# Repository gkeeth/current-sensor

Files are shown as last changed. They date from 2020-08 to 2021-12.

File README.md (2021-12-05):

# current-sensor
Hall effect current sensor board. Invasive (connected in series with DUT), with BNC output to oscilloscope.

Designed to fit in Hammond 1593W enclosure. Powered by 9V battery. Includes PCBs for front and back panels (20A and 36A options for front panel).

## Specifications:
- Output: 0-5V, DC-coupled
- Maximum input current: +/-20A. Different current limits are possible by
selecting a different version of the ACS730 Hall effect IC (also changes sensitivity)
  - ACS730xxxxx-20AB: +/- 20A
  - ACS730xxxxx-40AB: +/- 40A [limited to 36A by binding posts]
- Gain: selectable between x1, x10, and x100
  - -20AB: x1 (100mV/A), x10 (1V/A), and x100 (10V/A)
  - -40AB: x1 (50mV/A), x10 (500mV/A), and x100 (5V/A)
- Bandwidth: selectable between 1kHz, 10kHz, and 100kHz
- Power supply: 9V battery

## Adjustment Procedure:
The only adjustment needed is to adjust the zero-current offset voltage so that
the output reads zero when zero current is applied to the input.

1. Disconnect wires from input jacks so that input current is zero.
2. Set Gain to 1x and Bandwidth to 1kHz.
3. Adjust trimmer RV1 until the voltage at the output (between BNC center pin
and shell) is as close to 0V as possible.
4. Increase gain to 10x/100x and fine-tune adjustment.

## Possible Future Improvements:
- use a multi-turn trimpot for zero-current offset adjustment
- make adjustment trimpot available at rear panel for trim without removing case

## Schematic:
[PDF of schematic](pdf/current-sensor.pdf)
schematic

## Layout:
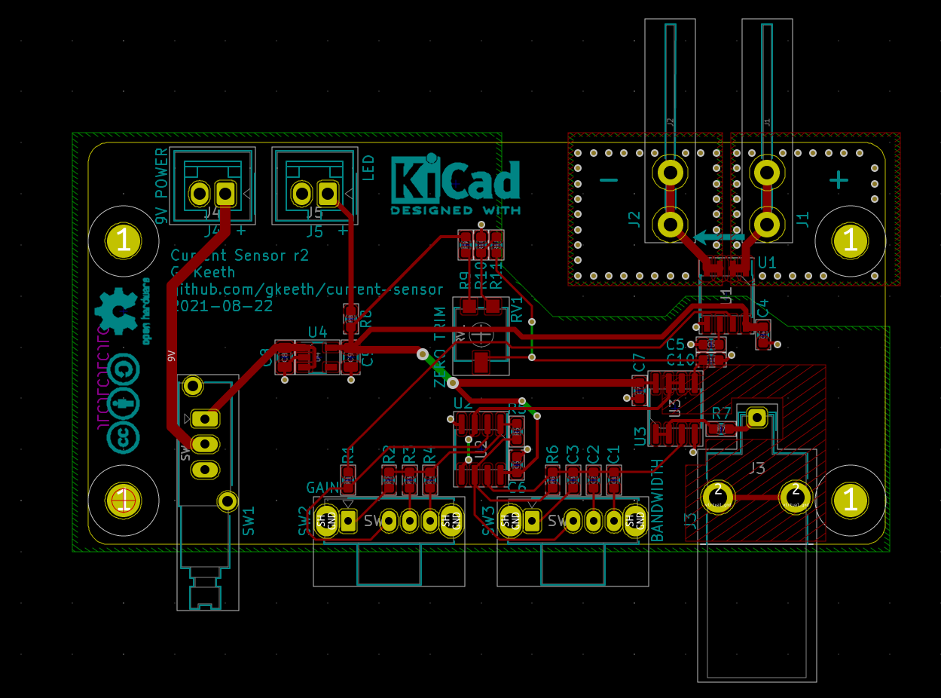
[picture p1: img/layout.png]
layout


## BOM:
[BOM for main board](bom/current-sensor.csv)

### Additional components:
Note that the board was designed with Molex SL crimp terminals for the LED and 9V battery,
but those connections could be done with another crimp family or even soldered. Substitute
connectors as appropriate.

| Quantity | Manufacturer | Manufacturer PN  | Distributor | Distributor PN | Notes |
| --- | --- | --- | --- | --- | --- |
| 1 | Hammond | 1593WBK | Digikey | 164-1593WBK-ND | case |
| 1 | Hammond | 1593ATS50 | Digikey | HM1442-ND | PCB mounting screws  |
| 1 | MPD | BH9VW | Digikey | BH9VW-ND | battery holder |
| 2 | Cal Test | CT2232-4 | Digikey | BKCT2232-4-ND  | binding posts |
| 1 | C&K | G003G | Digikey | 401-1205-ND | power button cap |
| 1 | Lumex | SSI-LXH312ID-150 | Digikey | 67-1190-ND | power LED |
| 2 | Molex | 0190050010 | Digikey | WM18241-ND | QC connectors |
| 4 | Molex | 0016020097 | Digikey | WM2513-ND | SL crimp terminals for LED and battery |
| 2 | Molex | 0050579402 | Digikey | WM2900-ND | SL crimp housings for LED and battery  |

## Front/Rear Panel and Assembly:
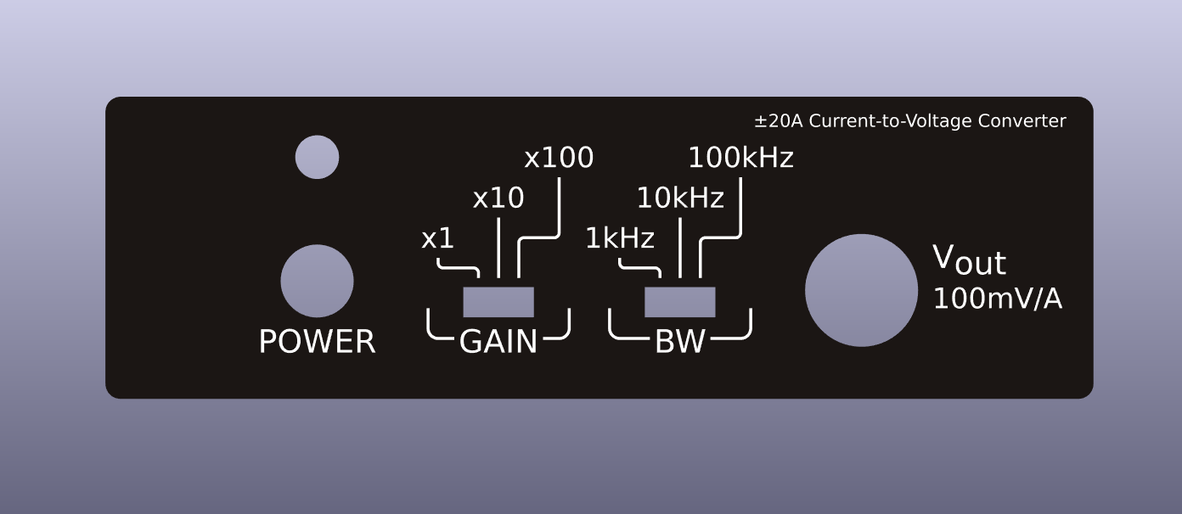
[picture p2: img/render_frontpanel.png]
front panel

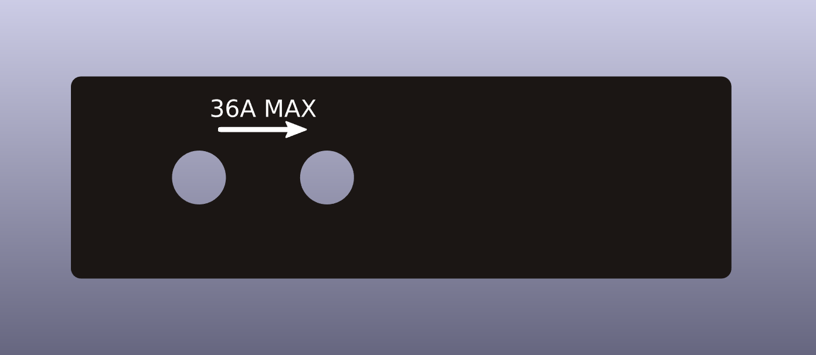
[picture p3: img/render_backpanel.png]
back panel

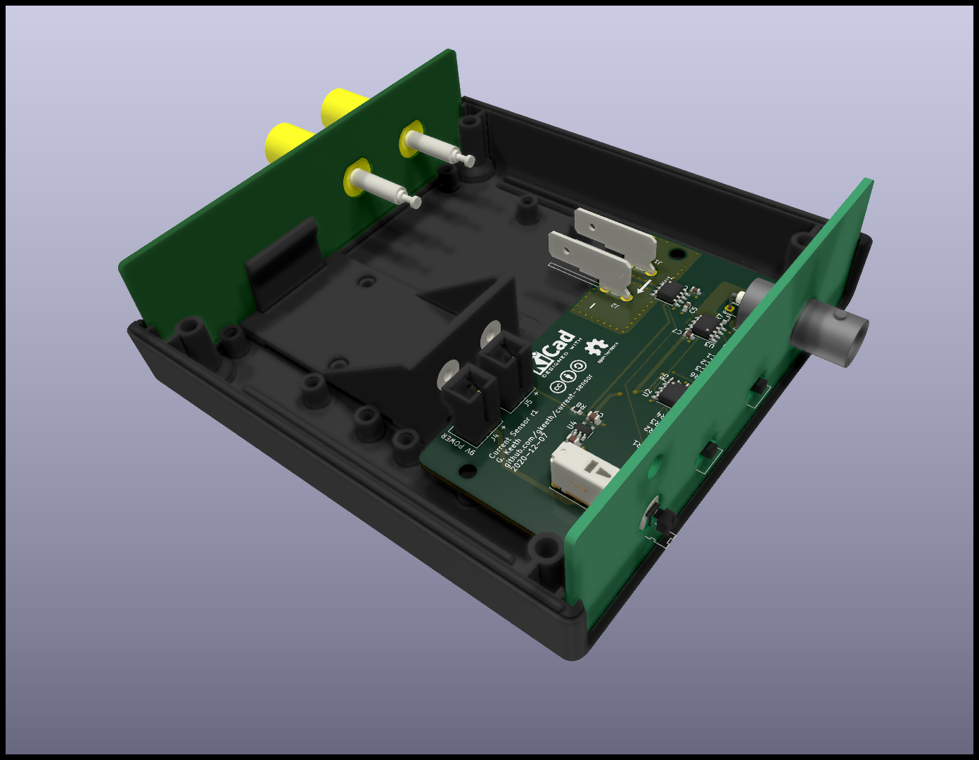
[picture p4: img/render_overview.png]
front render


## License:
Licensed under the [Creative Commons Attribution-ShareAlike 4.0 International License][cc-by-sa].

[][cc-by-sa]

[cc-by-sa]: http://creativecommons.org/licenses/by-sa/4.0/
[cc-by-sa-image]: https://licensebuttons.net/l/by-sa/4.0/88x31.png

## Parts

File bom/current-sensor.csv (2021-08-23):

Source: | /home/graham/Projects/current-sensor/current-sensor.sch
Date: | Mon 23 Aug 2021 08:48:15 AM EDT
Tool: | Eeschema 5.1.10
Generator: | /usr/share/kicad/plugins/bom_csv_grouped_by_value.py
Component Count: | 41
Individual Components:
Item | Qty | Reference(s) | Value | LibPart | Footprint | Datasheet | Distributor | Distributor PN | Manufacturer | Manufacturer PN
 |  | C1 | 150p | Device:C_Small | Capacitor_SMD:C_0603_1608Metric | ~
 |  | C2 | 1.5n | Device:C_Small | Capacitor_SMD:C_0603_1608Metric | ~
 |  | C3 | 15n | Device:C_Small | Capacitor_SMD:C_0603_1608Metric | ~
 |  | C4 | 100n | Device:C | Capacitor_SMD:C_0603_1608Metric | ~
 |  | C5 | 1n | Device:C | Capacitor_SMD:C_0603_1608Metric | ~
 |  | C6 | 100n | Device:C_Small | Capacitor_SMD:C_0603_1608Metric | ~
 |  | C7 | 100n | Device:C_Small | Capacitor_SMD:C_0603_1608Metric | ~
 |  | C8 | 1u | Device:C | Capacitor_SMD:C_0805_2012Metric | ~
 |  | C9 | 1u | Device:C | Capacitor_SMD:C_0805_2012Metric | ~
 |  | C10 | 100n | Device:C | Capacitor_SMD:C_0603_1608Metric | ~
 |  | H1 | MountingHole | Mechanical:MountingHole | MountingHole:MountingHole_3.2mm_M3 | ~
 |  | H2 | MountingHole | Mechanical:MountingHole | MountingHole:MountingHole_3.2mm_M3 | ~
 |  | H3 | MountingHole | Mechanical:MountingHole | MountingHole:MountingHole_3.2mm_M3 | ~
 |  | H4 | MountingHole | Mechanical:MountingHole | MountingHole:MountingHole_3.2mm_M3 | ~
 |  | J1 | ‎0197134001‎ | Connector:Conn_01x01_Male | Connector_Molex_Quixon:Connector_Molex_Quixon_19713-4001_1x01_Horizontal | ~ | Digikey | WM7391-ND | Molex | 0197134001
 |  | J2 | ‎0197134001‎ | Connector:Conn_01x01_Male | Connector_Molex_Quixon:Connector_Molex_Quixon_19713-4001_1x01_Horizontal | ~ | Digikey | WM7391-ND | Molex | 0197134001
 |  | J3 | 0731000105 | Connector:Conn_Coaxial | Connector_Coaxial_gkeeth:BNC_Molex_73100-0105_Horizontal | ~ | Digikey | WM5524-ND | Molex | 0731000105
 |  | J4 | Molex_SL_01x02_Male | Connector_gkeeth:Molex_SL_01x02_Male | Connector_Molex_SL:Molex_SL_A-70543-0001_1x02_P2.54mm_Vertical | https://www.molex.com/pdm_docs/sd/705430001_sd.pdf | Digikey | WM4800-ND | Molex | 0705430001
 |  | J5 | Molex_SL_01x02_Male | Connector_gkeeth:Molex_SL_01x02_Male | Connector_Molex_SL:Molex_SL_A-70543-0001_1x02_P2.54mm_Vertical | https://www.molex.com/pdm_docs/sd/705430001_sd.pdf | Digikey | WM4800-ND | Molex | 0705430001
 |  | LOGO1 | CC-BY-SA_0.5in | Creative_Commons:CC-BY-SA_0.5in | Symbol_CreativeCommons:CC-BY-SA_SilkScreenTop_Small
 |  | LOGO2 | Logo_MadeWithKiCad | Graphic_gkeeth:Logo_MadeWithKiCad | Symbol:KiCad-Logo2_6mm_SilkScreen
 |  | LOGO3 | Logo_Open_Hardware_Small | Graphic:Logo_Open_Hardware_Small | Symbol:OSHW-Logo2_7.3x6mm_SilkScreen | ~
 |  | R1 | 1k | Device:R | Resistor_SMD:R_0603_1608Metric | ~
 |  | R2 | 1k | Device:R | Resistor_SMD:R_0603_1608Metric | ~
 |  | R3 | 10k | Device:R | Resistor_SMD:R_0603_1608Metric | ~
 |  | R4 | 100k | Device:R | Resistor_SMD:R_0603_1608Metric | ~
 |  | R5 | 10k | Device:R | Resistor_SMD:R_0603_1608Metric | ~
 |  | R6 | 10k | Device:R | Resistor_SMD:R_0603_1608Metric | ~
 |  | R7 | 49.9 | Device:R | Resistor_SMD:R_0603_1608Metric | ~
 |  | R8 | 2.2k | Device:R | Resistor_SMD:R_0603_1608Metric | ~
 |  | R9 | 51k | Device:R | Resistor_SMD:R_0603_1608Metric | ~
 |  | R10 | 51k | Device:R | Resistor_SMD:R_0603_1608Metric | ~
 |  | R11 | 1M | Device:R | Resistor_SMD:R_0603_1608Metric | ~
 |  | RV1 | 10k | Device:R_POT_TRIM | Potentiometer_SMD:Potentiometer_Vishay_TS53YL_Vertical | ~ |  |  | Vishay Svernice | TS53YL103MR10
 |  | SW1 | PN12SHNA03QE | Switch_gkeeth:PN12Sxxx03QE | Button_Switch_THT_gkeeth:SW_Push_SPDT_CK_PN1xSxxx03QE | https://www.ckswitches.com/media/1413/pn.pdf | Digikey | CKN1189-ND | C&K | PN12SHNA03QE
 |  | SW2 | OS103011MA7QP1 | Switch_gkeeth:OS103011MA7QP1 | Button_Switch_THT_gkeeth:SW_Slide_SP3T_CK_OS103011MA7QP1 | https://www.ckswitches.com/media/1428/os.pdf | Digikey | CKN9561-ND | C&K | OS103011MA7QP1
 |  | SW3 | OS103011MA7QP1 | Switch_gkeeth:OS103011MA7QP1 | Button_Switch_THT_gkeeth:SW_Slide_SP3T_CK_OS103011MA7QP1 | https://www.ckswitches.com/media/1428/os.pdf | Digikey | CKN9561-ND | C&K | OS103011MA7QP1
 |  | U1 | ACS730xLCTR-20AB | Sensor_Current:ACS730xLCTR-20AB | Package_SO:SOIC-8_3.9x4.9mm_P1.27mm | http://www.allegromicro.com/~/media/Files/Datasheets/ACS730-Datasheet.ashx?la=en | Digikey | 620-1792-1-ND | Allegro Microsystems | ACS730KLCTR-20AB-T
 |  | U2 | AD8616xRM | Amplifier_Operational_gkeeth:AD8616xRM | Package_SO:SOIC-8_3.9x4.9mm_P1.27mm | https://www.analog.com/media/en/technical-documentation/data-sheets/AD8615_8616_8618.pdf | Digikey | AD8616ARZ-REEL7CT-ND | Analog Devices | AD8616ARZ-REEL7
 |  | U3 | AD8616xRM | Amplifier_Operational_gkeeth:AD8616xRM | Package_SO:SOIC-8_3.9x4.9mm_P1.27mm | https://www.analog.com/media/en/technical-documentation/data-sheets/AD8615_8616_8618.pdf | Digikey | AD8616ARZ-REEL7CT-ND | Analog Devices | AD8616ARZ-REEL7
 |  | U4 | NCP718ASN500 | Regulator_Linear_gkeeth:NCP718ASN500 | Package_TO_SOT_SMD:TSOT-23-5 | https://www.onsemi.com/pub/Collateral/NCP718-D.PDF | Digikey | NCP718ASN500T1GOSCT-ND | ON Semi | NCP718ASN500T1G
Collated Components:
Item | Qty | Reference(s) | Value | LibPart | Footprint | Datasheet | Distributor | Distributor PN | Manufacturer | Manufacturer PN
1 | 1 | C1 | 150p | Device:C_Small | Capacitor_SMD:C_0603_1608Metric | ~
2 | 1 | C2 | 1.5n | Device:C_Small | Capacitor_SMD:C_0603_1608Metric | ~
3 | 1 | C3 | 15n | Device:C_Small | Capacitor_SMD:C_0603_1608Metric | ~
4 | 2 | C4, C10 | 100n | Device:C | Capacitor_SMD:C_0603_1608Metric | ~
5 | 1 | C5 | 1n | Device:C | Capacitor_SMD:C_0603_1608Metric | ~
6 | 2 | C6, C7 | 100n | Device:C_Small | Capacitor_SMD:C_0603_1608Metric | ~
7 | 2 | C8, C9 | 1u | Device:C | Capacitor_SMD:C_0805_2012Metric | ~
8 | 4 | H1, H2, H3, H4 | MountingHole | Mechanical:MountingHole | MountingHole:MountingHole_3.2mm_M3 | ~
9 | 2 | J1, J2 | ‎0197134001‎ | Connector:Conn_01x01_Male | Connector_Molex_Quixon:Connector_Molex_Quixon_19713-4001_1x01_Horizontal | ~ | Digikey | WM7391-ND | Molex | 0197134001
10 | 1 | J3 | 0731000105 | Connector:Conn_Coaxial | Connector_Coaxial_gkeeth:BNC_Molex_73100-0105_Horizontal | ~ | Digikey | WM5524-ND | Molex | 0731000105
11 | 2 | J4, J5 | Molex_SL_01x02_Male | Connector_gkeeth:Molex_SL_01x02_Male | Connector_Molex_SL:Molex_SL_A-70543-0001_1x02_P2.54mm_Vertical | https://www.molex.com/pdm_docs/sd/705430001_sd.pdf | Digikey | WM4800-ND | Molex | 0705430001
12 | 1 | LOGO1 | CC-BY-SA_0.5in | Creative_Commons:CC-BY-SA_0.5in | Symbol_CreativeCommons:CC-BY-SA_SilkScreenTop_Small
13 | 1 | LOGO2 | Logo_MadeWithKiCad | Graphic_gkeeth:Logo_MadeWithKiCad | Symbol:KiCad-Logo2_6mm_SilkScreen
14 | 1 | LOGO3 | Logo_Open_Hardware_Small | Graphic:Logo_Open_Hardware_Small | Symbol:OSHW-Logo2_7.3x6mm_SilkScreen | ~
15 | 2 | R1, R2 | 1k | Device:R | Resistor_SMD:R_0603_1608Metric | ~
16 | 3 | R3, R5, R6 | 10k | Device:R | Resistor_SMD:R_0603_1608Metric | ~
17 | 1 | R4 | 100k | Device:R | Resistor_SMD:R_0603_1608Metric | ~
18 | 1 | R7 | 49.9 | Device:R | Resistor_SMD:R_0603_1608Metric | ~
19 | 1 | R8 | 2.2k | Device:R | Resistor_SMD:R_0603_1608Metric | ~
20 | 2 | R9, R10 | 51k | Device:R | Resistor_SMD:R_0603_1608Metric | ~
21 | 1 | R11 | 1M | Device:R | Resistor_SMD:R_0603_1608Metric | ~
22 | 1 | RV1 | 10k | Device:R_POT_TRIM | Potentiometer_SMD:Potentiometer_Vishay_TS53YL_Vertical | ~ |  |  | Vishay Svernice | TS53YL103MR10
23 | 1 | SW1 | PN12SHNA03QE | Switch_gkeeth:PN12Sxxx03QE | Button_Switch_THT_gkeeth:SW_Push_SPDT_CK_PN1xSxxx03QE | https://www.ckswitches.com/media/1413/pn.pdf | Digikey | CKN1189-ND | C&K | PN12SHNA03QE
24 | 2 | SW2, SW3 | OS103011MA7QP1 | Switch_gkeeth:OS103011MA7QP1 | Button_Switch_THT_gkeeth:SW_Slide_SP3T_CK_OS103011MA7QP1 | https://www.ckswitches.com/media/1428/os.pdf | Digikey | CKN9561-ND | C&K | OS103011MA7QP1
25 | 1 | U1 | ACS730xLCTR-20AB | Sensor_Current:ACS730xLCTR-20AB | Package_SO:SOIC-8_3.9x4.9mm_P1.27mm | http://www.allegromicro.com/~/media/Files/Datasheets/ACS730-Datasheet.ashx?la=en | Digikey | 620-1792-1-ND | Allegro Microsystems | ACS730KLCTR-20AB-T
26 | 2 | U2, U3 | AD8616xRM | Amplifier_Operational_gkeeth:AD8616xRM | Package_SO:SOIC-8_3.9x4.9mm_P1.27mm | https://www.analog.com/media/en/technical-documentation/data-sheets/AD8615_8616_8618.pdf | Digikey | AD8616ARZ-REEL7CT-ND | Analog Devices | AD8616ARZ-REEL7
27 | 1 | U4 | NCP718ASN500 | Regulator_Linear_gkeeth:NCP718ASN500 | Package_TO_SOT_SMD:TSOT-23-5 | https://www.onsemi.com/pub/Collateral/NCP718-D.PDF | Digikey | NCP718ASN500T1GOSCT-ND | ON Semi | NCP718ASN500T1G

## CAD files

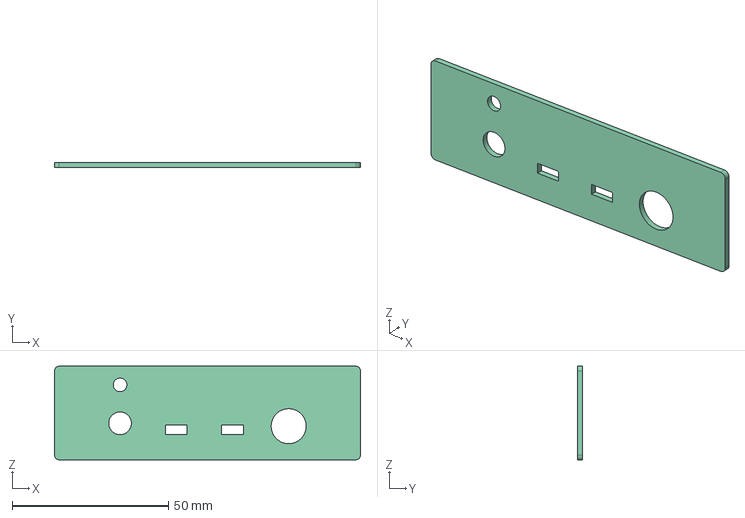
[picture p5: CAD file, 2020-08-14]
mechanical/current-sensor-frontpanel_sp.step
98.0 x 1.60 x 30.0 mm

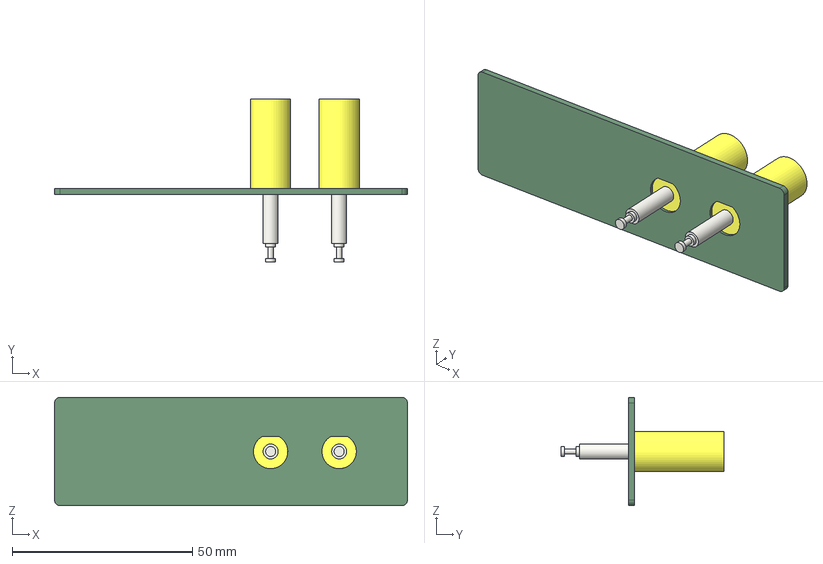
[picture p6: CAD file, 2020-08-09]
mechanical/current-sensor-backpanel_sp.step
98.0 x 45.2 x 30.0 mm

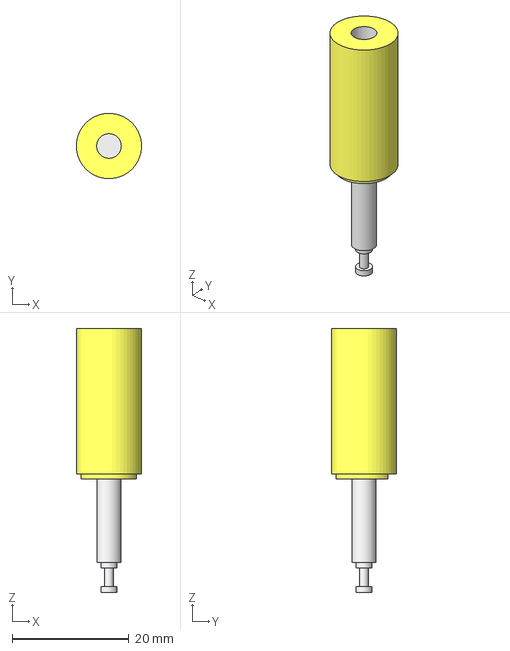
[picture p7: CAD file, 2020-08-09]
mechanical/3760-4.step
11.2 x 11.2 x 45.2 mm

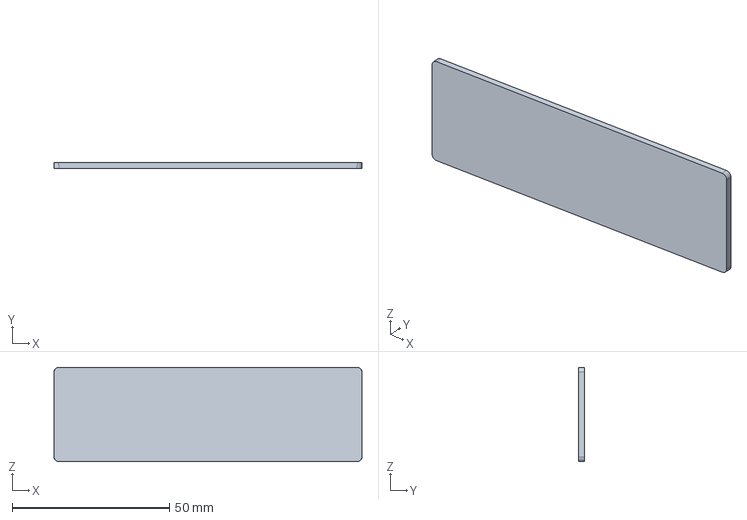
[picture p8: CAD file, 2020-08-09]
mechanical/1593w_front_nocutouts.step
98.0 x 1.80 x 30.0 mm

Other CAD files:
mechanical/1593w_back_nocutouts.step
mechanical/3760-4.FCStd

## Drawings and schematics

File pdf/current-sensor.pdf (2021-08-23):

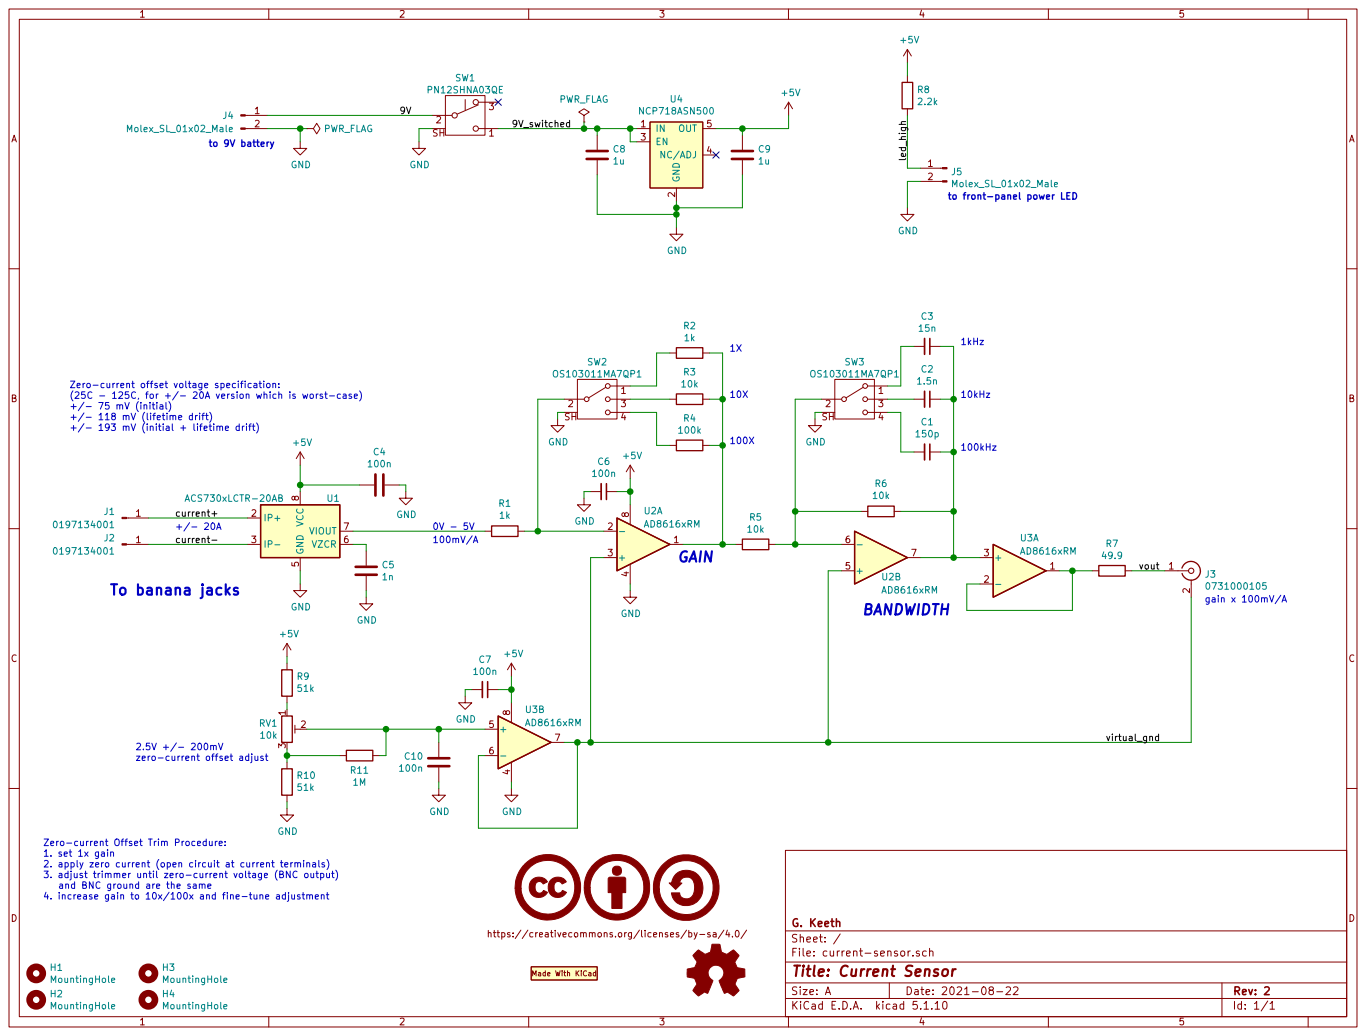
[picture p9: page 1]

2 EN 3 NC/ADJ 4 OUT 5 U4 NCP718ASN500

Zero-current offset voltage specification:
(25C - 125C, for +/- 20A version which is worst-case)
+/- 75 mV (initial)
+/- 118 mV (lifetime drift)
+/- 193 mV (initial + lifetime drift)

AD8616xRM
https://creativecommons.org/licenses/by-sa/4.0/ V- 4 V+

Id: 1/1 Title: Current Sensor File: current-sensor.sch Sheet: / G. Keeth GND

4. increase gain to 10x/100x and fine-tune adjustment 2.5V +/- 200mV

zero-current offset adjust

Zero-current Offset Trim Procedure: 1. set 1x gain

2. apply zero current (open circuit at current terminals)
3. adjust trimmer until zero-current voltage (BNC output)
and BNC ground are the same

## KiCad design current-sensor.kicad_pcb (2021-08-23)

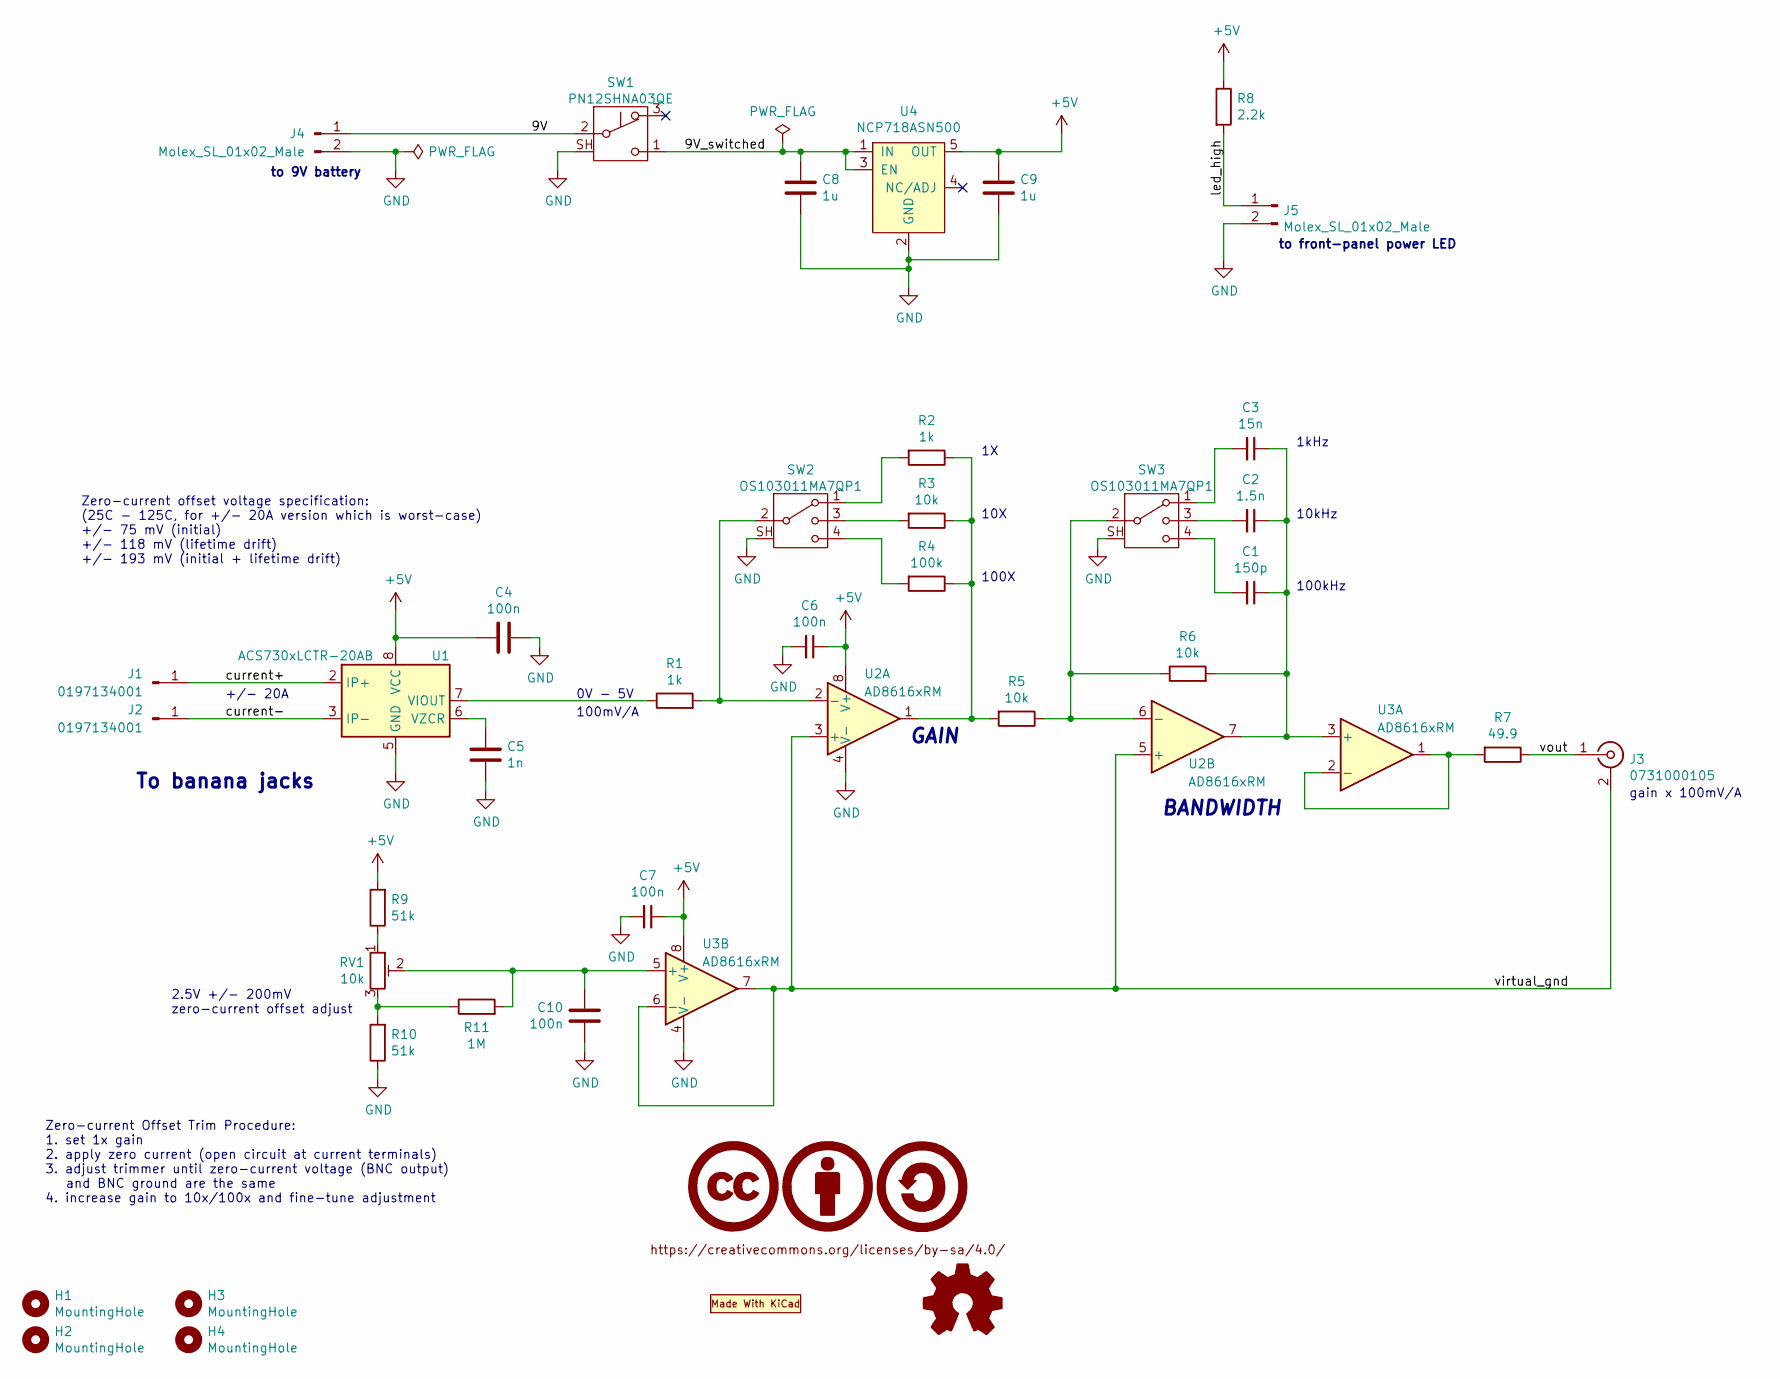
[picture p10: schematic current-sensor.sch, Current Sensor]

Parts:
C1: 150p; C_0603_1608Metric
C2: 1.5n; C_0603_1608Metric
C3: 15n; C_0603_1608Metric
C4, C6, C7, C10: 100n; C_0603_1608Metric
C5: 1n; C_0603_1608Metric
C8, C9: 1u; C_0805_2012Metric
H1, H2, H3, H4: MountingHole; MountingHole_3.2mm_M3
J1, J2: ‎0197134001‎; Connector_Molex_Quixon_19713-4001_1x01_Horizontal; Manufacturer PN 0197134001
J3: 0731000105; BNC_Molex_73100-0105_Horizontal; Manufacturer PN 0731000105
J4, J5: Molex_SL_01x02_Male; Molex_SL_A-70543-0001_1x02_P2.54mm_Vertical; Manufacturer PN 0705430001
LOGO1: CC-BY-SA_0.5in; CC-BY-SA_SilkScreenTop_Small
LOGO2: Logo_MadeWithKiCad; KiCad-Logo2_6mm_SilkScreen
LOGO3: Logo_Open_Hardware_Small; OSHW-Logo2_7.3x6mm_SilkScreen
R1, R2: 1k; R_0603_1608Metric
R3, R5, R6: 10k; R_0603_1608Metric
R4: 100k; R_0603_1608Metric
R7: 49.9; R_0603_1608Metric
R8: 2.2k; R_0603_1608Metric
R9, R10: 51k; R_0603_1608Metric
R11: 1M; R_0603_1608Metric
RV1: 10k; Potentiometer_Vishay_TS53YL_Vertical; Manufacturer PN TS53YL103MR10
SW1: PN12SHNA03QE; SW_Push_SPDT_CK_PN1xSxxx03QE; Manufacturer PN PN12SHNA03QE
SW2, SW3: OS103011MA7QP1; SW_Slide_SP3T_CK_OS103011MA7QP1; Manufacturer PN OS103011MA7QP1
U1: ACS730xLCTR-20AB; SOIC-8_3.9x4.9mm_P1.27mm; Manufacturer PN ACS730KLCTR-20AB-T
U2, U3: AD8616xRM; SOIC-8_3.9x4.9mm_P1.27mm; Manufacturer PN AD8616ARZ-REEL7
U4: NCP718ASN500; TSOT-23-5; Manufacturer PN NCP718ASN500T1G

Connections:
+5V: C4.2, C6.1, C7.1, C9.1, R8.1, R9.2, U1.8 (VCC), U2.8 (V+), U3.8 (V+), U4.5 (OUT)
/9V: J4.1, SW1.2 (B)
/9V_switched: C8.1, SW1.1 (C), U4.1 (IN), U4.3 (EN)
/current+: J1.1, U1.1 (IP+), U1.2 (IP+)
/current-: J2.1, U1.3 (IP-), U1.4 (IP-)
/led_high: J5.1, R8.2
/virtual_gnd: J3.2 (Ext), U2.3 (+), U2.5 (+), U3.6 (-), U3.7
/vout: J3.1 (In), R7.1
GND: C4.1, C5.2, C6.2, C7.2, C8.2, C9.2, C10.2, J4.2, J5.2, R10.1, SW1.SH, SW2.SH, SW3.SH, U1.5 (GND), U2.4 (V-), U3.4 (V-), U4.2 (GND)
unnamed: C1.1, C2.1, C3.1, R6.2, U2.7, U3.3 (+)
unnamed: C1.2, SW3.4
unnamed: C2.2, SW3.3
unnamed: C3.2, SW3.1
unnamed: C5.1, U1.6 (VZCR)
unnamed: C10.1, R11.2, RV1.2, U3.5 (+)
unnamed: R1.1, U1.7 (VIOUT)
unnamed: R1.2, SW2.2, U2.2 (-)
unnamed: R2.1, R3.1, R4.1, R5.2, U2.1
unnamed: R2.2, SW2.1
unnamed: R3.2, SW2.3
unnamed: R4.2, SW2.4
unnamed: R5.1, R6.1, SW3.2, U2.6 (-)
unnamed: R7.2, U3.1, U3.2 (-)
unnamed: R9.1, RV1.1
unnamed: R10.2, R11.1, RV1.3

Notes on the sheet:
0V - 5V
10X
100X
100kHz
10kHz
1kHz
To banana jacks
GAIN
BANDWIDTH
to front-panel power LED
to 9V battery
100mV/A
+/- 20A
gain x 100mV/A
Zero-current Offset Trim Procedure: 1. set 1x gain 2. apply zero current (open circuit at current terminals) 3. adjust trimmer until zero-current voltage (BNC output) and BNC ground are the same 4. increase gain to 10x/100x and fine-tune adjustment
2.5V +/- 200mV zero-current offset adjust
Zero-current offset voltage specification: (25C - 125C, for +/- 20A version which is worst-case) +/- 75 mV (initial) +/- 118 mV (lifetime drift) +/- 193 mV (initial + lifetime drift)

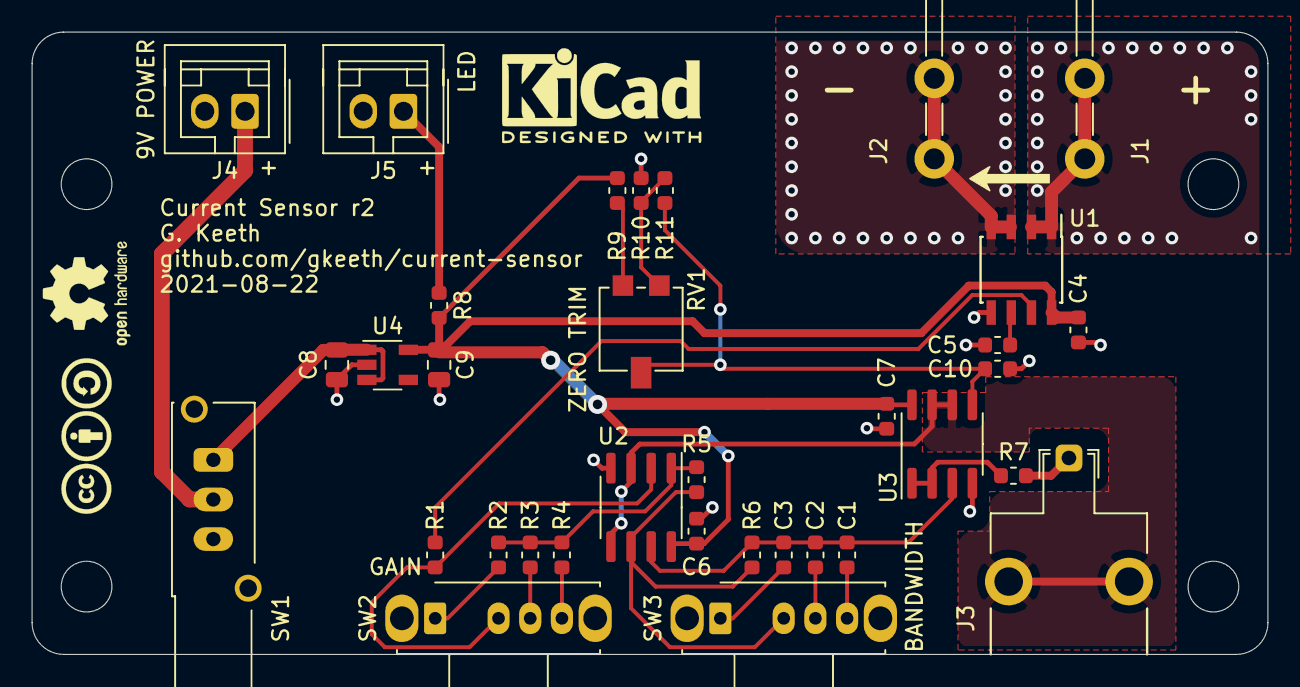
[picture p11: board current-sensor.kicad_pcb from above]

Board: 2 copper layers, 78.0 x 39.3 mm, 41 parts (0 on the bottom side), 25 nets.

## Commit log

2020-07-01 initial schematic design
    [current-sensor.kicad_pcb, current-sensor.sch]
2020-07-02 fix opamp power unit annotation
    [current-sensor.sch]
2020-08-04 mostly complete schematic and initial placement
    [current-sensor.kicad_pcb, current-sensor.sch]
2020-08-07 add mechanical models for enclosure, battery holder, and binding posts
    [current-sensor.kicad_pcb, current-sensor.sch]
2020-08-09 update 3d models in main board
    [current-sensor.kicad_pcb]
2020-08-09 add pcb project for back panel
    [current-sensor-backpanel.kicad_pcb, current-sensor-backpanel.sch]
2020-08-09 Add mechanical 3d models
    all 3d models added are licensed identically to the rest of the project
    (CC-BY-SA). Manufacturer 3d models are not tracked in the repository
    because they are restrictively licensed.
    [1593w_back_nocutouts.step, 1593w_front_nocutouts.step, 3760-4.FCStd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]
2020-08-09 update paths for 3d models
    [current-sensor-backpanel.kicad_pcb]
2020-08-14 complete mechanical placement of all components on main pcb, and holes on front/back panels
    [current-sensor-backpanel.kicad_pcb, current-sensor-backpanel.sch, current-sensor-frontpanel.kicad_pcb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]
2020-08-14 update README with enclosure details
2020-08-25 complete basic schematic & routing
    [current-sensor.kicad_pcb, current-sensor.sch]
2020-08-25 thicken traces
    [current-sensor.kicad_pcb, current-sensor.sch]
2020-08-25 remove note about #4 clearance hole size
    [current-sensor.sch]
2020-08-25 update titleblocks
    [current-sensor.kicad_pcb, current-sensor.sch]
2020-08-25 add power flag to GND and add PDF schematic
    [current-sensor.sch]
2020-08-25 add battery details to readme
2020-08-25 pcb churn from plotting
    [current-sensor.kicad_pcb]
2020-10-18 swap 100kHz and 1kHz bandwidth positions
    [current-sensor.kicad_pcb, current-sensor.sch]
2020-10-18 Change hall effect sensor to +/-20A
    binding posts are limited to 15A. Decrease hall effect sensor range to
    lowest available (+/-20A).
    It is possible to use the equivalent part with a higher current range,
    but the connectors would need to be modified and the overall system gain
    would decrease due to reduced sensor sensitivity.
    [current-sensor.sch]
2020-10-18 update pcb with hall effect sensor PN change
    [current-sensor.kicad_pcb]
2020-10-18 add switch mockup and update silk lines
2020-10-23 complete front panel label
    [current-sensor-frontpanel.kicad_pcb, current-sensor-frontpanel.sch]
2020-10-26 add draft back panel label; missing current arrow
2020-10-26 add back panel label
    [current-sensor-backpanel.kicad_pcb, current-sensor-backpanel.sch]
2020-10-26 adjust planes around current connectors and add silk
    [current-sensor.kicad_pcb, current-sensor.sch]
2020-10-27 add name of instrument to front panel
    [current-sensor-frontpanel.kicad_pcb]
2020-10-27 add 36A version of frontpanel footprint
2020-10-27 update text on backpanel to 36A Max (binding post limit)
    [current-sensor-backpanel.kicad_pcb]
2020-10-29 update backpanel footprint
2020-10-29 generate gerbers for backpanel
    [current-sensor-backpanel-B_Cu.gbr, current-sensor-backpanel-B_Mask.gbr, current-sensor-backpanel-B_SilkS.gbr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]
2020-10-29 generate gerbers for 36A and 20A frontpanel
    [current-sensor-frontpanel-B_Cu.gbr, current-sensor-frontpanel-B_Mask.gbr, current-sensor-frontpanel-B_SilkS.gbr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]
2020-10-30 decrease solder mask clearance to 0 as recommended
    [current-sensor.kicad_pcb]
2020-10-30 add JLC order number silk
    [current-sensor.kicad_pcb]
2020-10-30 add JLC order number text to backpanel
    [current-sensor-backpanel.kicad_pcb]
2020-10-30 update backpanel gerbers with JLC order number text
    [current-sensor-backpanel-B_Cu.gbr, current-sensor-backpanel-B_Mask.gbr, current-sensor-backpanel-B_SilkS.gbr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]
2020-10-30 add gerbers for main pcb
    [current-sensor-B_Cu.gbr, current-sensor-B_Mask.gbr, current-sensor-B_SilkS.gbr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]
2020-11-10 add fab/silk polarity marks to led/power connectors
    [current-sensor.kicad_pcb]
2020-11-10 add interactive HTML bom
2020-11-10 label power/LED connectors
    [current-sensor.kicad_pcb]
2020-11-10 update ibom with connector labels
2020-11-10 fix C8 silk position
    [current-sensor.kicad_pcb]
2020-12-08 revision 1 of current sensor
    - fix gain/bandwidth switch pin numbering
    - move faston connectors further apart
    - switch from MSOP to SOIC package for op-amp
    - add silk labels to switches and connectors
    - reduce LED resistor to increase brightness
    [current-sensor.kicad_pcb, current-sensor.sch]
2020-12-14 update gerbers for rev1 main pcb
    [current-sensor-B_Cu.gbr, current-sensor-B_Mask.gbr, current-sensor-B_SilkS.gbr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]
2020-12-14 update schematic plots, renders, and readme
2020-12-14 ignore gerber zips
2020-12-14 add ordering info to schematic
    [current-sensor.sch]
2020-12-14 add bom
    [current-sensor.csv]
2020-12-16 add BOM to readme
2020-12-16 remove duplicated led in BOM
2021-01-04 add zero-current offset trim
    [current-sensor.kicad_pcb, current-sensor.sch]
2021-08-23 Change offset trim circuit
    completely ignore reference output from current sensor IC. Instead, use
    trimpot to get 2.5V +/- 200mV reference voltage.
    [current-sensor.kicad_pcb, current-sensor.sch]
2021-08-23 generate gerbers for r2
    [current-sensor-B_Cu.gbr, current-sensor-B_Mask.gbr, current-sensor-B_SilkS.gbr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]
2021-08-23 regenerate schematic/layout svg/pdf/png plots
2021-08-23 update bom for r2
    [current-sensor.csv]
